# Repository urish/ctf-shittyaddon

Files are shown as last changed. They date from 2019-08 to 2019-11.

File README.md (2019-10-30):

# Minimal Shitty Add-On with Capture The Flag Challenge

Copyright (C) 2019, Uri Shaked. Released under the MIT license.

[__Learn more in the blog post: Capture The Flag Shitty Add-On__](https://blog.wokwi.com/capture-the-flag-shitty-add-on/?utm_source=github)

## Hardware

The [ctf-shittyaddon board](pcb/) includes the following hardware:

1. ATtiny85 Processor
2. A [ShittyAddon V1](https://twitter.com/MrRobotBadge/status/962043056781324289) connector 
3. Reset button
4. Red LED connected to ATtiny85's pin 6 (PB1)

Tiny CTF PCB

You can also hack a simplified version on a breadboard:

Arduino Connection Diagram

## Firmware

Compile the firmware using the Arduino IDE:

1. Install [ATTiny Core](https://github.com/damellis/attiny)
2. Install the [TinyWire Library](https://github.com/lucullusTheOnly/TinyWire)
3. Configure Arduino IDE as follows:
   - Board: ATtiny25/45/85
   - Processor: ATtiny85
   - Clock: Internal 8 MHz
4. Set the fuses of the chip to enable self programming (`SELFPRGEN=1`). 
   This can be done using `avrdude`:
   ```bash
   avrdude -pattiny85 -cusbtiny -e -Uefuse:w:0xfe:m -Uhfuse:w:0xdf:m -Ulfuse:w:0xe2:m
   ```

When building your own firmware, replace `SECRET` in the string `"$FLAG:SECRET"` 
with your secret value (the flag).

## The Challenge

The [firmware code](ctf-firmware/ctf-firmware.ino) implements an I2C slave listening on address 0x23.

The challenge consists of several milestones of increasing difficulty:

1. Make the red LED light
2. Find the secret flag value (it starts with the string "$FLAG:")
3. Make the red LED blink by executing code directly on the ATTiny85
4. Replace the secret flag with a new value without bricking the board

All the above milestones can be achieved through I2C communication with
the chip.

For more information, [check out the blog post](https://blog.wokwi.com/capture-the-flag-shitty-add-on/?utm_source=github)

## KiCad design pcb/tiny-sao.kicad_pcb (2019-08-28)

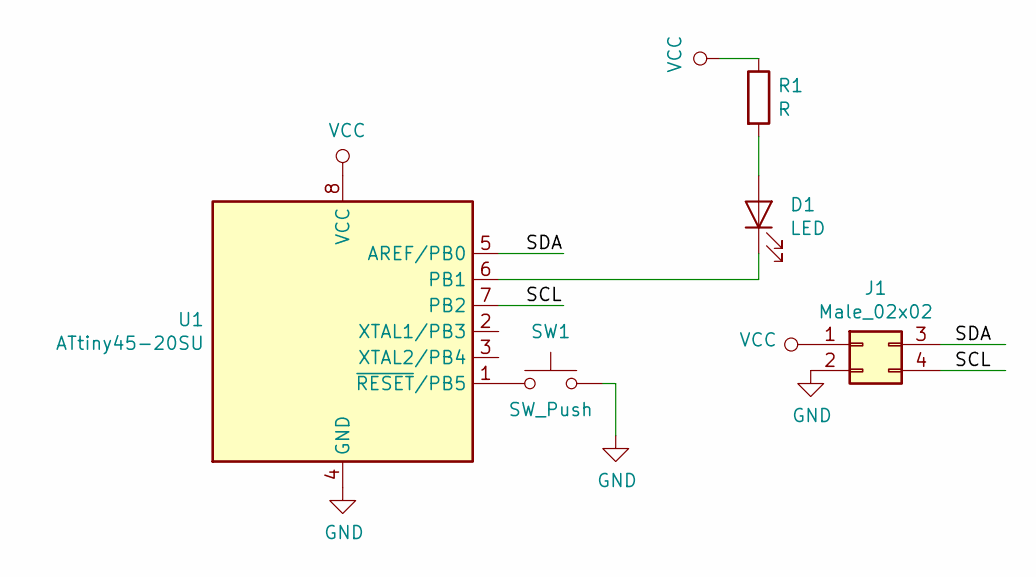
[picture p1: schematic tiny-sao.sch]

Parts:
D1: LED; LED_0603_1608Metric
J1: Male_02x02; PinHeader_2x02_P2.54mm_Vertical
R1: R; R_0603_1608Metric
SW1: SW_Push; TACTILE-SWITCH-1101NE
U1: ATtiny45-20SU; SOIJ-8_5.3x5.3mm_P1.27mm

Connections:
/SCL: J1.4, U1.7 (PB2)
/SDA: J1.3, U1.5 (AREF/PB0)
GND: J1.2, SW1.2, U1.4 (GND)
unnamed: D1.1 (K), U1.6 (PB1)
unnamed: D1.2 (A), R1.2
unnamed: SW1.1, U1.1 (~RESET~/PB5)
VCC: J1.1, R1.1, U1.8 (VCC)

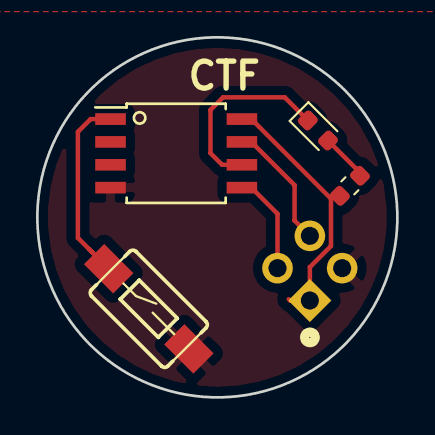
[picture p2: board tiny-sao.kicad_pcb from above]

Board: 2 copper layers, 20.0 x 20.0 mm, 5 parts (1 on the bottom side), 7 nets.

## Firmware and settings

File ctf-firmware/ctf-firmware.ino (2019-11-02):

/**
 * Capture-The-Flag ShittyAddon Firmware
 * Copyright (C) 2019, Uri Shaked
 * Released under the MIT license.
 */

// LED is connected to PB1

#include <avr/boot.h>
#include <TinyWire.h>

uint16_t target = 0;
uint16_t flash_addr = 0x400;
uint16_t flash_value = 0x20;

// SECRET will be replaced with the actual flag:
const char flag[] PROGMEM = "$FLAG:SECRET"; 

void setup() {
  TinyWire.begin(0x23);
  TinyWire.onReceive(onI2CReceive);
  TinyWire.onRequest(onI2CRequest);
  for (uint8_t ch = 0; flag[ch]; ch++) {
    flash_value ^= flag[ch];
  }  
}

void loop() {
  bool erase = flash_addr & 0x8000;
  flash_addr &= 0x1fff;
  if (flash_addr >= 0x800) {
    cli();
    if (erase) {
      boot_page_erase_safe(flash_addr);
    } else {
      for (uint8_t i = 0; i < SPM_PAGESIZE; i += 2, flash_value += 2) {
        boot_page_fill_safe(flash_addr + i, *(uint16_t*)flash_value);      
      }
      boot_page_write(flash_addr);
    }
    boot_spm_busy_wait();
    flash_addr = 0;
    sei();
  }
}

void onI2CReceive(int cnt) {
  target = TinyWire.read();
  while (TinyWire.available()) {
    *(uint8_t*)target++ = TinyWire.read();    
  }
}

void onI2CRequest() {
  TinyWire.send(target);
  uint8_t* addr = (uint8_t*)((target++) & 0x1fff);
  TinyWire.send((target & 0x8000) ? pgm_read_byte(addr): *addr);
}
  

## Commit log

2019-08-28 fix(pcb): SCL and SDA were crossed
    [tiny-sao.kicad_pcb, tiny-sao.sch]
2019-08-28 feat(pcb): indicate VCC with a circle
    per ShittyAddon V1 standard
    [tiny-sao.kicad_pcb]
2019-11-02 fix(firmware): add missing typecast
    Makes the compiler happy, see https://twitter.com/manekinekko/status/1190696892910444544 for details
    [ctf-firmware.ino]
